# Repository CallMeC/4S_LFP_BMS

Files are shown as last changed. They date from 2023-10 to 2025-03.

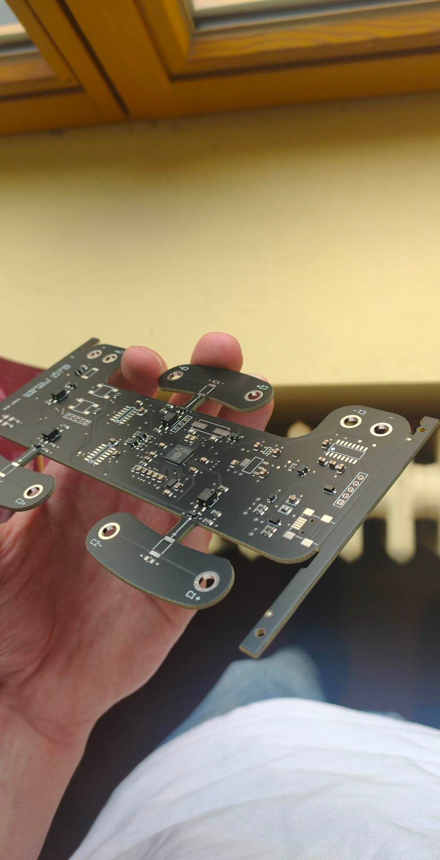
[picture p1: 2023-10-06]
Photos/NEW.jpg

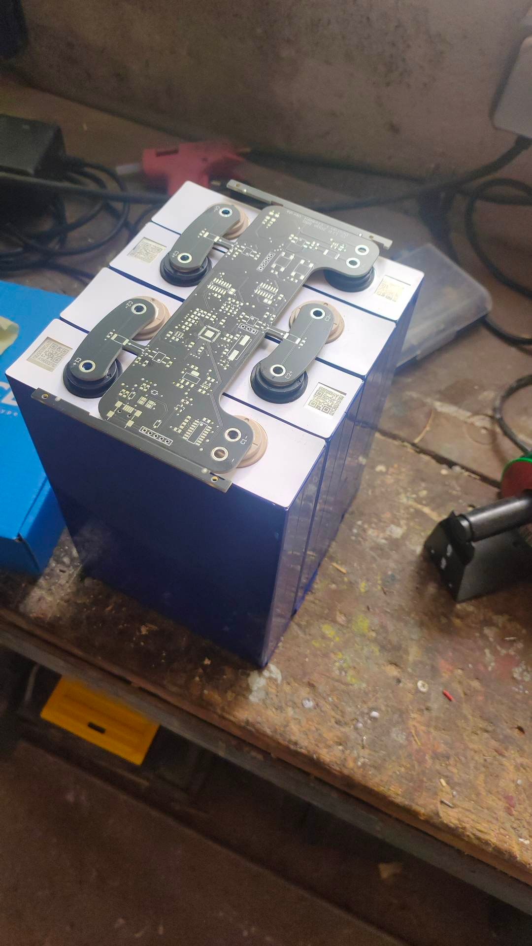
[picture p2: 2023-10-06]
Photos/ON_CELLS.jpg

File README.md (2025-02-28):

# 4S Lithium Iron Phosphate BMS RP2040 based
This BMS is intented to be used with EVE LF105 LFP cells. It goes on top of them, and is attached thanks to screws. The busbar is inside the PCB.

# Capabilities
The BMS can output up to 200A continuously and 400 peak. I tried to jumpstart a car, it works without problem.
The output voltage depends on capacity, a connctor was placed in order to add a daughter card to add USB-C power delivery capability.

# Features
This BMS is ables to :
- charge / discharge cells independently
- monitor voltage of each cell
- monitor temperature of group of cells
- monitor current accurately thanks to an inside shunt

# Performance
The BMS has the following characteristics :
- 4S Lithium Capability (LiFePO4)
- 12V Power Output
- 200A Continuous & 400A Peak current capability
- 1A Balancing current
- High accuracy cell voltage measurement
- Cell temperature measurement
- High accuracy current measurement
- Daisy-chaining capability (in case of pack)
- CAN 2.0 Communication
- Deep-Sleep mode with auto wake-up capbility
- Computer monitoring
- Active balancing extension board
- EEPROM

# Software
This BMS is based on the RP2040, the software is in early stage and not fully functionnal and tested yet.
Nevertheless, it can communicate to a computer by UART through USB. This way we can easily monitor the different cells caracteristics.

# Preview
2024-07-21-15-53-03-ezgif com-optimize

QT C++ Programm to visualise BMS characteristics in real time.

Assembly View

TOP_VIEW

SIDE_VIEW

PCB Preview


Capture d'écran 2024-02-19 112637




# Thanks
Thanks to @Ustan26 for his great help reviewing code !

# License
MIT License

Copyright (c) 2024 Clément VERDA

Permission is hereby granted, free of charge, to any person obtaining a copy
of this software and associated documentation files (the "Software"), to deal
in the Software without restriction, including without limitation the rights
to use, copy, modify, merge, publish, distribute, sublicense, and/or sell
copies of the Software, and to permit persons to whom the Software is
furnished to do so, subject to the following conditions:

The above copyright notice and this permission notice shall be included in all
copies or substantial portions of the Software.

THE SOFTWARE IS PROVIDED "AS IS", WITHOUT WARRANTY OF ANY KIND, EXPRESS OR
IMPLIED, INCLUDING BUT NOT LIMITED TO THE WARRANTIES OF MERCHANTABILITY,
FITNESS FOR A PARTICULAR PURPOSE AND NONINFRINGEMENT. IN NO EVENT SHALL THE
AUTHORS OR COPYRIGHT HOLDERS BE LIABLE FOR ANY CLAIM, DAMAGES OR OTHER
LIABILITY, WHETHER IN AN ACTION OF CONTRACT, TORT OR OTHERWISE, ARISING FROM,
OUT OF OR IN CONNECTION WITH THE SOFTWARE OR THE USE OR OTHER DEALINGS IN THE
SOFTWARE.

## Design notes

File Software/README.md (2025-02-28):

# Software
You will find here :
- BMS firmware
- Computer user-interface

This project utilizes work from the following GitHub repository: 
 
1. [Repository 1 URL](https://github.com/KevinOConnor/can2040) by [KevinOConnor ](https://github.com/KevinOConnor) 
   - Used the canRP2040 lib from this repository for CAN implementation on RP2040 MCU. 
   - Licensed under the GPL-3.0 license.

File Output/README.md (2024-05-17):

# PCB
Here are the PCB files of the v1.
A v2 is on the way.

# PCB Stackup
The PCB is intended to be manufactured by JLCPCB on a 4 layer stackup.
The outer layers should be at least 70µm copper height.
The inner layers should be at least 35 µm.
This allows the use of PCB for a busbar.

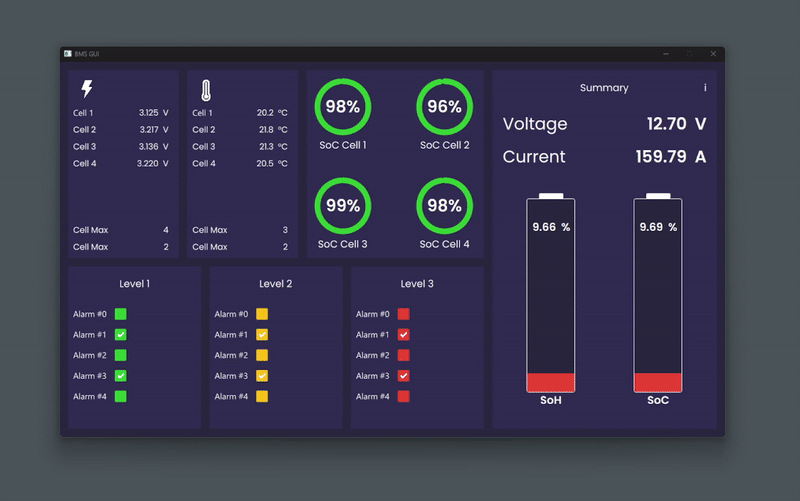
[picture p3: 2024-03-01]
Photos/BMS_GUI_PREVIEW.gif

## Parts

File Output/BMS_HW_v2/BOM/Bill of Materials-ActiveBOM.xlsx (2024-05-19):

Name | Designator | LCSC_Part_# | Description
CC0805KRX7R8BB104 | C1 | C49678 | CAP CER 0.1UF 25V X7R 0805
CC0805KRX7R8BB104 | C2 | C49678 | CAP CER 0.1UF 25V X7R 0805
CC0805KRX7R8BB104 | C3 | C49678 | CAP CER 0.1UF 25V X7R 0805
CL21A106KACLRNC | C4 | C49678 | CL21 Series 0805 10uF 25V ±10% Tolerance X5R Multilayer Ceramic Chip Capacitor
CL21A106KACLRNC | C5 |  | CL21 Series 0805 10uF 25V ±10% Tolerance X5R Multilayer Ceramic Chip Capacitor
CL21A106KACLRNC | C6 | C88484 | CL21 Series 0805 10uF 25V ±10% Tolerance X5R Multilayer Ceramic Chip Capacitor
CL21A106KACLRNC | C7 | C49678 | CL21 Series 0805 10uF 25V ±10% Tolerance X5R Multilayer Ceramic Chip Capacitor
CL21A106KACLRNC | C8 | C437557 | CL21 Series 0805 10uF 25V ±10% Tolerance X5R Multilayer Ceramic Chip Capacitor
CL21A106KACLRNC | C9 | C49678 | CL21 Series 0805 10uF 25V ±10% Tolerance X5R Multilayer Ceramic Chip Capacitor
CL21A106KACLRNC | C10 | C88484 | CL21 Series 0805 10uF 25V ±10% Tolerance X5R Multilayer Ceramic Chip Capacitor
CC0805KRX7R8BB104 | C11 | C28323 | CAP CER 0.1UF 25V X7R 0805
CC0805KRX7R8BB104 | C12 | C28323 | CAP CER 0.1UF 25V X7R 0805
CL21A106KACLRNC | C13 | C49678 | CL21 Series 0805 10uF 25V ±10% Tolerance X5R Multilayer Ceramic Chip Capacitor
CC0805KRX7R8BB104 | C14 | C377773 | CAP CER 0.1UF 25V X7R 0805
CC0805KRX7R8BB104 | C15 | C49678 | CAP CER 0.1UF 25V X7R 0805
CC0805KRX7R8BB104 | C16 | C377773 | CAP CER 0.1UF 25V X7R 0805
CC0805KRX7R8BB104 | C17 | C49678 | CAP CER 0.1UF 25V X7R 0805
CC0805KRX7R8BB104 | C18 | C49678 | CAP CER 0.1UF 25V X7R 0805
CC0805KRX7R8BB104 | C19 | C377773 | CAP CER 0.1UF 25V X7R 0805
CC0805KRX7R8BB104 | C20 | C49678 | CAP CER 0.1UF 25V X7R 0805
CC0805KRX7R8BB104 | C21 | C49678 | CAP CER 0.1UF 25V X7R 0805
CC0805KRX7R8BB104 | C22 | C49678 | CAP CER 0.1UF 25V X7R 0805
CC0805KRX7R8BB104 | C23 | C49678 | CAP CER 0.1UF 25V X7R 0805
CC0805KRX7R8BB104 | C24 | C49678 | CAP CER 0.1UF 25V X7R 0805
CC0805KRX7R8BB104 | C25 | C49678 | CAP CER 0.1UF 25V X7R 0805
CC0805KRX7R8BB104 | C26 | C49678 | CAP CER 0.1UF 25V X7R 0805
CC0805KRX7R8BB104 | C27 | C1808 | CAP CER 0.1UF 25V X7R 0805
CC0805KRX7R8BB104 | C28 | C1808 | CAP CER 0.1UF 25V X7R 0805
CC0805KRX7R8BB104 | C29 | C377773 | CAP CER 0.1UF 25V X7R 0805
CL21A106KACLRNC | C30 | C961512 | CL21 Series 0805 10uF 25V ±10% Tolerance X5R Multilayer Ceramic Chip Capacitor
CL21A106KACLRNC | C31 | C49678 | CL21 Series 0805 10uF 25V ±10% Tolerance X5R Multilayer Ceramic Chip Capacitor
CL21A106KACLRNC | C32 | C961512 | CL21 Series 0805 10uF 25V ±10% Tolerance X5R Multilayer Ceramic Chip Capacitor
CC0805KRX7R8BB104 | C33 | C49678 | CAP CER 0.1UF 25V X7R 0805
CL21A106KACLRNC | C34 | C88484 | CL21 Series 0805 10uF 25V ±10% Tolerance X5R Multilayer Ceramic Chip Capacitor
CL21A106KACLRNC | C35 | C49678 | CL21 Series 0805 10uF 25V ±10% Tolerance X5R Multilayer Ceramic Chip Capacitor
CC0805KRX7R8BB104 | C36 | C49678 | CAP CER 0.1UF 25V X7R 0805
CC0805KRX7R8BB104 | C37 | C49678 | CAP CER 0.1UF 25V X7R 0805
CC0805KRX7R8BB104 | C38 | C49678 | CAP CER 0.1UF 25V X7R 0805
CC0805KRX7R8BB104 | C39 | C49678 | CAP CER 0.1UF 25V X7R 0805
CC0805KRX7R8BB104 | C40 | C49678 | CAP CER 0.1UF 25V X7R 0805
CC0805KRX7R8BB104 | C41 | C49678 | CAP CER 0.1UF 25V X7R 0805
CC0805KRX7R8BB104 | C42 | C49678 | CAP CER 0.1UF 25V X7R 0805
CC0805KRX7R8BB104 | C43 | C1710 | CAP CER 0.1UF 25V X7R 0805
CC0805KRX7R8BB104 | C44 | C1710 | CAP CER 0.1UF 25V X7R 0805
CC0805KRX7R8BB104 | C45 | C1710 | CAP CER 0.1UF 25V X7R 0805
CC0805KRX7R8BB104 | C46 | C1710 | CAP CER 0.1UF 25V X7R 0805
CC0805KRX7R8BB104 | C47 | C1710 | CAP CER 0.1UF 25V X7R 0805
CC0805KRX7R8BB104 | C48 | C49678 | CAP CER 0.1UF 25V X7R 0805
CC0805KRX7R8BB104 | C49 | C49678 | CAP CER 0.1UF 25V X7R 0805
CC0805KRX7R8BB104 | C50 | C49678 | CAP CER 0.1UF 25V X7R 0805
LF105 Cell Terminal | Cell1- |  | LF105 Cell Terminal
LF105 Cell Terminal | Cell1+ |  | LF105 Cell Terminal
LF105 Cell Terminal | Cell2- |  | LF105 Cell Terminal
LF105 Cell Terminal | Cell2+ |  | LF105 Cell Terminal
LF105 Cell Terminal | Cell3- |  | LF105 Cell Terminal
LF105 Cell Terminal | Cell3+ |  | LF105 Cell Terminal
LF105 Cell Terminal | Cell4- |  | LF105 Cell Terminal
LF105 Cell Terminal | Cell4+ |  | LF105 Cell Terminal
ZMM3V3 | D1 |  | Zener ZMM3V3
B340AE-13 | D2 | C168859 | Rectifier Diode, Schottky, 1 Phase, 1 Element, 3A, 40V V(RRM), Silicon
B340AE-13 | D3 | C168859 | Rectifier Diode, Schottky, 1 Phase, 1 Element, 3A, 40V V(RRM), Silicon
82356050050 | D4 | C9900055762
HSMG-C170 | D5 | C84256 | Chip LED, Green, 2.2 V, -40 to 85 degC, 2-Pin SMD, Pb-Free, Tape and Reel
SS14 | D6 | C2480 | DIODE SCHOTTKY 40V 1A SMA
SS14 | D7 | C2480 | DIODE SCHOTTKY 40V 1A SMA
SS14 | D8 | C2480 | DIODE SCHOTTKY 40V 1A SMA
TPD2E2U06DCKR | D9 | C1855726 | Q100 TO CATALOG SPIN OF TPD2E2U0
HSMG-C170 | D10 | C84256 | Chip LED, Green, 2.2 V, -40 to 85 degC, 2-Pin SMD, Pb-Free, Tape and Reel
LF105 Cell Terminal | J1 |  | LF105 Cell Terminal
LF105 Cell Terminal | J2 |  | LF105 Cell Terminal
87224-3 | J3 |  | Board Connector, 3 Contact(s), 1 Row(s), Male, Straight, 0.1 inch Pitch, Solder Terminal, Black Insulator, Receptacle
22-27-2021 | J4 | C293316 | Male Header, Pitch 2.54 mm, 1 x 2 Position, Height 11.7 mm, Tail Length 3.56 mm, 0 to 75 degC, RoHS, Bulk
1565749-4 | J5 |  | Automotive Connectors 025 4POS CAP ASY SELECTIVE-TIN
MUSB-05-S-B-SM-A | J6 | C5362859 | CONN RCPT USB2.0 MINI B SMD R/A
1565749-4 | J7 |  | Automotive Connectors 025 4POS CAP ASY SELECTIVE-TIN
TSW-104-08-L-S | J8 |  | Board Connector, 4 Contact(s), 1 Row(s), Male, Straight, Solder Terminal
90120-0125 | J9 |  | 90120-0125 2.54mm Pitch C-Grid III Header, Single Row, Vertical, 5 Circuits, Tin (Sn) Plating
SRR1260-5R6Y | L1 | C2761913 | General Purpose Inductor, 5.6uH, 30%, 1 Element, Ferrite-Core, SMD, 4949
BSS138 | Q1 | C112239 | N-Channel Logic Level Enhancement Mode Field Effect Transistor, 220 mA, 50 V, -55 to 150 degC, 3-Pin SOT-23, RoHS, Tape and Reel
BSS138 | Q2 | C112239 | N-Channel Logic Level Enhancement Mode Field Effect Transistor, 220 mA, 50 V, -55 to 150 degC, 3-Pin SOT-23, RoHS, Tape and Reel
BSS138 | Q3 | C112239 | N-Channel Logic Level Enhancement Mode Field Effect Transistor, 220 mA, 50 V, -55 to 150 degC, 3-Pin SOT-23, RoHS, Tape and Reel
AO3400A | Q4 | C20917 | MOSFET N-CH 30V 5.7A SOT23
AO3400A | Q5 | C20917 | MOSFET N-CH 30V 5.7A SOT23
AO3400A | Q6 | C20917 | MOSFET N-CH 30V 5.7A SOT23
AO3400A | Q7 | C20917 | MOSFET N-CH 30V 5.7A SOT23
BSS138 | Q8 | C112239 | N-Channel Logic Level Enhancement Mode Field Effect Transistor, 220 mA, 50 V, -55 to 150 degC, 3-Pin SOT-23, RoHS, Tape and Reel
RT0805DRE074K7L | R1 | C149504 | RES SMD 4.7K OHM 0.5% 1/8W 0805
RT0805DRE074K7L | R2 | C149504 | RES SMD 4.7K OHM 0.5% 1/8W 0805
RT0805DRE074K7L | R3 | C149504 | RES SMD 4.7K OHM 0.5% 1/8W 0805
RT0805DRE074K7L | R4 | C149504 | RES SMD 4.7K OHM 0.5% 1/8W 0805
RT0805DRE074K7L | R5 |  | RES SMD 4.7K OHM 0.5% 1/8W 0805
RT0805DRE074K7L | R6 | C95968 | RES SMD 4.7K OHM 0.5% 1/8W 0805
RT0805DRE074K7L | R7 | C95968 | RES SMD 4.7K OHM 0.5% 1/8W 0805
RT0805DRE074K7L | R8 | C95968 | RES SMD 4.7K OHM 0.5% 1/8W 0805
RT0805DRE074K7L | R9 | C95968 | RES SMD 4.7K OHM 0.5% 1/8W 0805
RT0805DRE074K7L | R10 | C17470 | RES SMD 4.7K OHM 0.5% 1/8W 0805
RT0805DRE074K7L | R11 | C2828840 | RES SMD 4.7K OHM 0.5% 1/8W 0805
RT0805DRE074K7L | R12 | C17621 | RES SMD 4.7K OHM 0.5% 1/8W 0805
RT0805DRE074K7L | R13 | C17414 | RES SMD 4.7K OHM 0.5% 1/8W 0805
RT0805DRE074K7L | R14 | C17414 | RES SMD 4.7K OHM 0.5% 1/8W 0805
RT0805DRE074K7L | R15 | C17414 | RES SMD 4.7K OHM 0.5% 1/8W 0805
RT0805DRE074K7L | R16 | C17414 | RES SMD 4.7K OHM 0.5% 1/8W 0805
PCB_SHUNT_200A | R17 |  | Shunt
RT0805DRE074K7L | R18 | C2828840 | RES SMD 4.7K OHM 0.5% 1/8W 0805
RT0805DRE074K7L | R19 | C17621 | RES SMD 4.7K OHM 0.5% 1/8W 0805
RT0805DRE074K7L | R20 | C2828840 | RES SMD 4.7K OHM 0.5% 1/8W 0805
RT0805DRE074K7L | R21 | C218616 | RES SMD 4.7K OHM 0.5% 1/8W 0805
RT0805DRE074K7L | R22 | C17414 | RES SMD 4.7K OHM 0.5% 1/8W 0805
RT0805DRE074K7L | R23 | C4382 | RES SMD 4.7K OHM 0.5% 1/8W 0805
RT0805DRE074K7L | R24 | C17513 | RES SMD 4.7K OHM 0.5% 1/8W 0805
RT0805DRE074K7L | R25 | C17414 | RES SMD 4.7K OHM 0.5% 1/8W 0805
RT0805DRE074K7L | R26 |  | RES SMD 4.7K OHM 0.5% 1/8W 0805
RT0805DRE074K7L | R27 |  | RES SMD 4.7K OHM 0.5% 1/8W 0805
RT0805DRE074K7L | R28 | C17594 | RES SMD 4.7K OHM 0.5% 1/8W 0805
RT0805DRE074K7L | R29 | C17594 | RES SMD 4.7K OHM 0.5% 1/8W 0805
RT0805DRE074K7L | R30 |  | RES SMD 4.7K OHM 0.5% 1/8W 0805
RT0805DRE074K7L | R31 | C17414 | RES SMD 4.7K OHM 0.5% 1/8W 0805
RT0805DRE074K7L | R32 | C25271 | RES SMD 4.7K OHM 0.5% 1/8W 0805
RT0805DRE074K7L | R33 | C17540 | RES SMD 4.7K OHM 0.5% 1/8W 0805
35224R7JT | R34 | C3924519 | Fixed Resistor, Metal Glaze/thick Film, 3W, 4.7ohm, 250V, 5% +/-Tol, 400ppm/Cel, Surface Mount, 2512
35224R7JT | R35 | C3924519 | Fixed Resistor, Metal Glaze/thick Film, 3W, 4.7ohm, 250V, 5% +/-Tol, 400ppm/Cel, Surface Mount, 2512
RT0805DRE074K7L | R36 | C17655 | RES SMD 4.7K OHM 0.5% 1/8W 0805
RT0805DRE074K7L | R37 | C17655 | RES SMD 4.7K OHM 0.5% 1/8W 0805
RT0805DRE074K7L | R38 | C17408 | RES SMD 4.7K OHM 0.5% 1/8W 0805
RT0805DRE074K7L | R39 | C17408 | RES SMD 4.7K OHM 0.5% 1/8W 0805
RT0805DRE074K7L | R40 | C865503 | RES SMD 4.7K OHM 0.5% 1/8W 0805
RT0805DRE074K7L | R41 | C149504 | RES SMD 4.7K OHM 0.5% 1/8W 0805
RT0805DRE074K7L | R42 | C865503 | RES SMD 4.7K OHM 0.5% 1/8W 0805
RT0805DRE074K7L | R43 | C149504 | RES SMD 4.7K OHM 0.5% 1/8W 0805
35224R7JT | R44 | C3924519 | Fixed Resistor, Metal Glaze/thick Film, 3W, 4.7ohm, 250V, 5% +/-Tol, 400ppm/Cel, Surface Mount, 2512
RT0805DRE074K7L | R45 | C17655 | RES SMD 4.7K OHM 0.5% 1/8W 0805
RT0805DRE074K7L | R46 | C17408 | RES SMD 4.7K OHM 0.5% 1/8W 0805
RT0805DRE074K7L | R47 | C865503 | RES SMD 4.7K OHM 0.5% 1/8W 0805
RT0805DRE074K7L | R48 | C149504 | RES SMD 4.7K OHM 0.5% 1/8W 0805
35224R7JT | R49 | C3924519 | Fixed Resistor, Metal Glaze/thick Film, 3W, 4.7ohm, 250V, 5% +/-Tol, 400ppm/Cel, Surface Mount, 2512
RT0805DRE074K7L | R50 | C17655 | RES SMD 4.7K OHM 0.5% 1/8W 0805
RT0805DRE074K7L | R51 | C17408 | RES SMD 4.7K OHM 0.5% 1/8W 0805
RT0805DRE074K7L | R52 | C865503 | RES SMD 4.7K OHM 0.5% 1/8W 0805
RT0805DRE074K7L | R53 | C149504 | RES SMD 4.7K OHM 0.5% 1/8W 0805
RT0805DRE074K7L | R54 | C17757 | RES SMD 4.7K OHM 0.5% 1/8W 0805
RT0805DRE074K7L | R55 | C17757 | RES SMD 4.7K OHM 0.5% 1/8W 0805
RT0805DRE074K7L | R56 |  | RES SMD 4.7K OHM 0.5% 1/8W 0805
RT0805DRE074K7L | R57 | C17408 | RES SMD 4.7K OHM 0.5% 1/8W 0805
RT0805DRE074K7L | R58 | C149504 | RES SMD 4.7K OHM 0.5% 1/8W 0805
RT0805DRE074K7L | R59 | C17655 | RES SMD 4.7K OHM 0.5% 1/8W 0805
RT0805DRE074K7L | R60 | C865503 | RES SMD 4.7K OHM 0.5% 1/8W 0805
FSM4JSMATR | SW1 |  | Micro Miniature Push Button Switch FSM JSM, 50 mA, -35 to 85 degC, 4-Pin SMD, RoHS, Tape and Reel
FSM4JSMATR | SW2 |  | Micro Miniature Push Button Switch FSM JSM, 50 mA, -35 to 85 degC, 4-Pin SMD, RoHS, Tape and Reel
FSM4JSMATR | SW3 |  | Micro Miniature Push Button Switch FSM JSM, 50 mA, -35 to 85 degC, 4-Pin SMD, RoHS, Tape and Reel
Test point | TP1 |  | test point
Test point | TP2 |  | test point
Test point | TP3 |  | test point
Test point | TP4 |  | test point
Test point | TP5 |  | test point
Test point | TP6 |  | test point
Test point | TP7 |  | test point
Test point | TP8 |  | test point
Test point | TP9 |  | test point
Test point | TP10 |  | test point
Test point | TP11 |  | test point
Test point | TP12 |  | test point
Test point | TP13 |  | test point
Test point | TP14 |  | test point
Test point | TP15 |  | test point
Test point | TP16 |  | test point
Test point | TP17 |  | test point
Test point | TP18 |  | test point
Test point | TP19 |  | test point
Test point | TP20 |  | test point
Test point | TP21 |  | test point
Test point | TP22 |  | test point
Test point | TP23 |  | test point
Test point | TP24 |  | test point
Test point | TP25 |  | test point
Test point | TP26 |  | test point
Test point | TP27 |  | test point
Test point | TP28 |  | test point
Test point | TP30 |  | test point
Test point | TP31 |  | test point
Test point | TP32 |  | test point
Test point | TP33 |  | test point
Test point | TP34 |  | test point
Test point | TP35 |  | test point
Test point | TP36 |  | test point
Test point | TP37 |  | test point
Test point | TP38 |  | test point
Test point | TP39 |  | test point
Test point | TP40 |  | test point
Test point | TP41 |  | test point
MCP3424-E/SL | U1 | C640884 | 18-Bit, 4-Channel Analog-to-Digital Converter with I2C Interface and On-Board Reference, 14-Pin SOIC 150mil, Extended Temperature
INA180A1IDBVR | U2 | C116203 | IC CURR SENSE 1 CIRCUIT SOT23-5
MCP3424-E/SL | U3 | C640884 | 18-Bit, 4-Channel Analog-to-Digital Converter with I2C Interface and On-Board Reference, 14-Pin SOIC 150mil, Extended Temperature
TPS563300DRLR | U4 | C3200405 | TPS563300 3.8-V to 28-V, 3-A Synchronous Buck Converter in SOT583 Package
TPL5110DDCT | U5 | C125830 | IC OSC PROG TIMER TSOT23-6
AP2112M-3.3TRG1 | U6 | C5290219 | Fixed Positive LDO Regulator, 3.3V, 0.4V Dropout, CMOS, PDSO8
RP2040 | U7 | C2040 | RP2040 chip for Raspberry Pi Pico - ARMÂ® CortexÂ®-M0+ MCU 32-Bit
W25Q16JVUXIQ | U8 |  | IC FLASH 16MBIT SPI/QUAD 8USON
FODM217CR2V | U9 | C891189 | Transistor Output Optocoupler, 1-Element, 3750V Isolation
FODM217CR2V | U10 | C891189 | Transistor Output Optocoupler, 1-Element, 3750V Isolation
FODM217CR2V | U11 | C891189 | Transistor Output Optocoupler, 1-Element, 3750V Isolation
FODM217CR2V | U12 | C891189 | Transistor Output Optocoupler, 1-Element, 3750V Isolation
SN65HVD230DR | U13 | C12084 | Interface Circuit, 1-Trnsvr, BICMOS, PDSO8
FODM217CR2V | U14 | C891189 | Transistor Output Optocoupler, 1-Element, 3750V Isolation
AT24C32D-SSHM-B | U15 |  | IC EEPROM 32KBIT I2C 1MHZ 8SOIC
FL1200138 | X1 | C526612 | 12 MHz +/-15ppm Crystal 8pF 120 Ohms 4-SMD, No Lead

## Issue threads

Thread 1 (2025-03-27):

Docs: HowTo use in series?

hansbkk, 2025-03-27:
for 24V or 48V

If impossible, please state 12V design only

CallMeC, 2025-03-27:
Hi!
A single battery pack is 12V, and is meant to be used in series with other packs, only CAN communication and wakeup wire is needed.
I will update documentation accordingly.
Thanks!

Closed 2025-03-27.

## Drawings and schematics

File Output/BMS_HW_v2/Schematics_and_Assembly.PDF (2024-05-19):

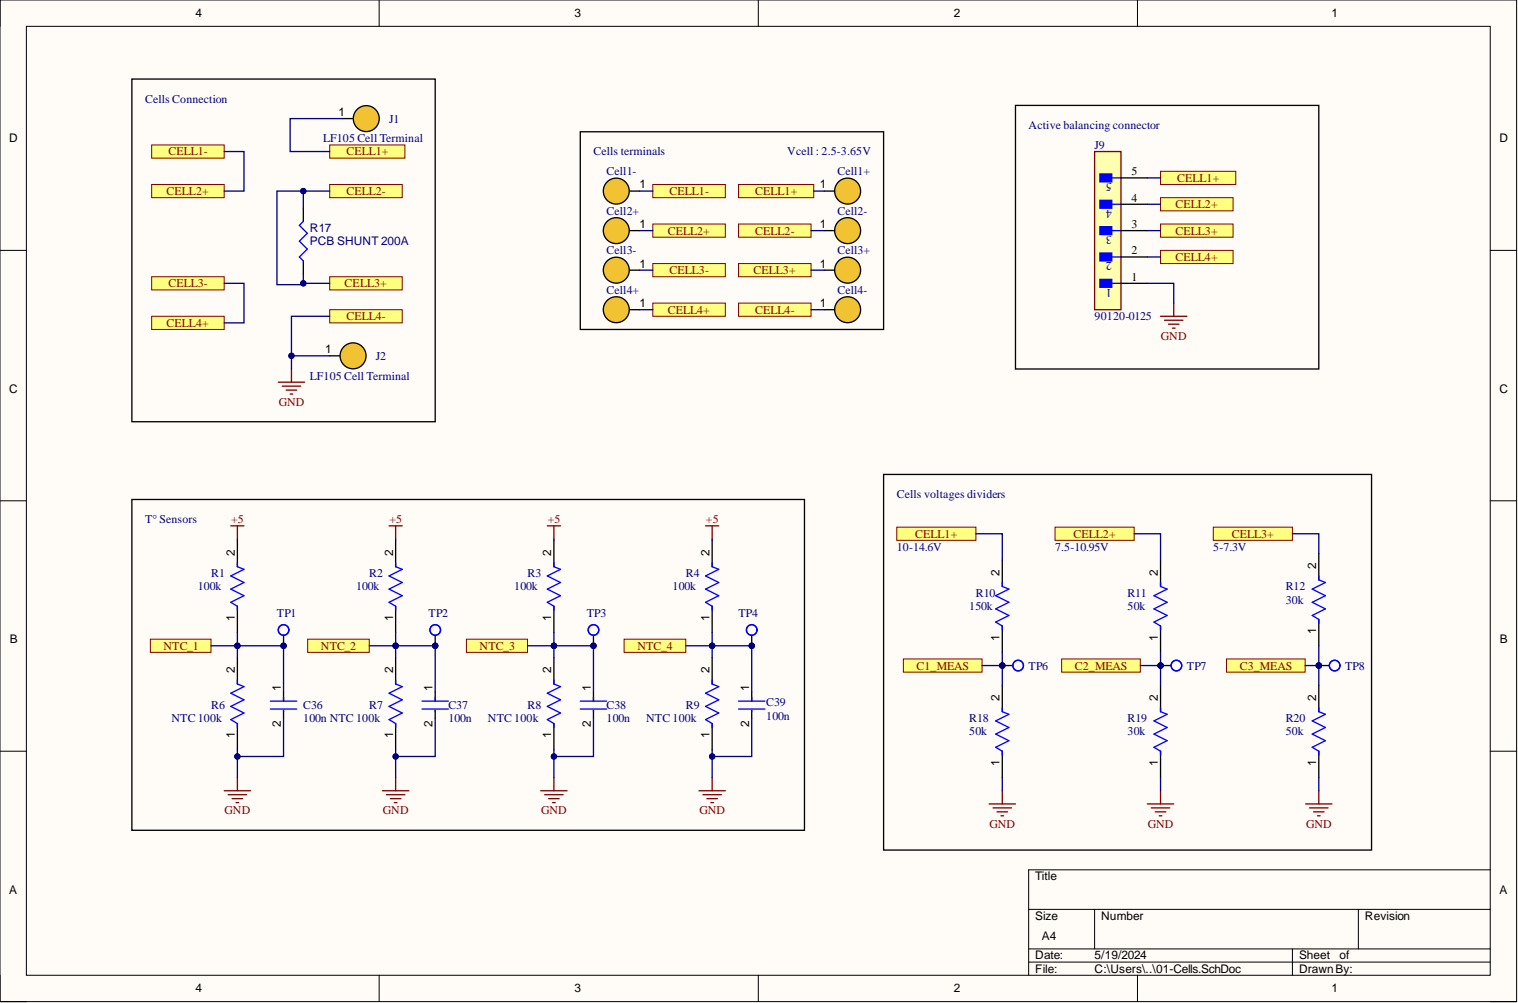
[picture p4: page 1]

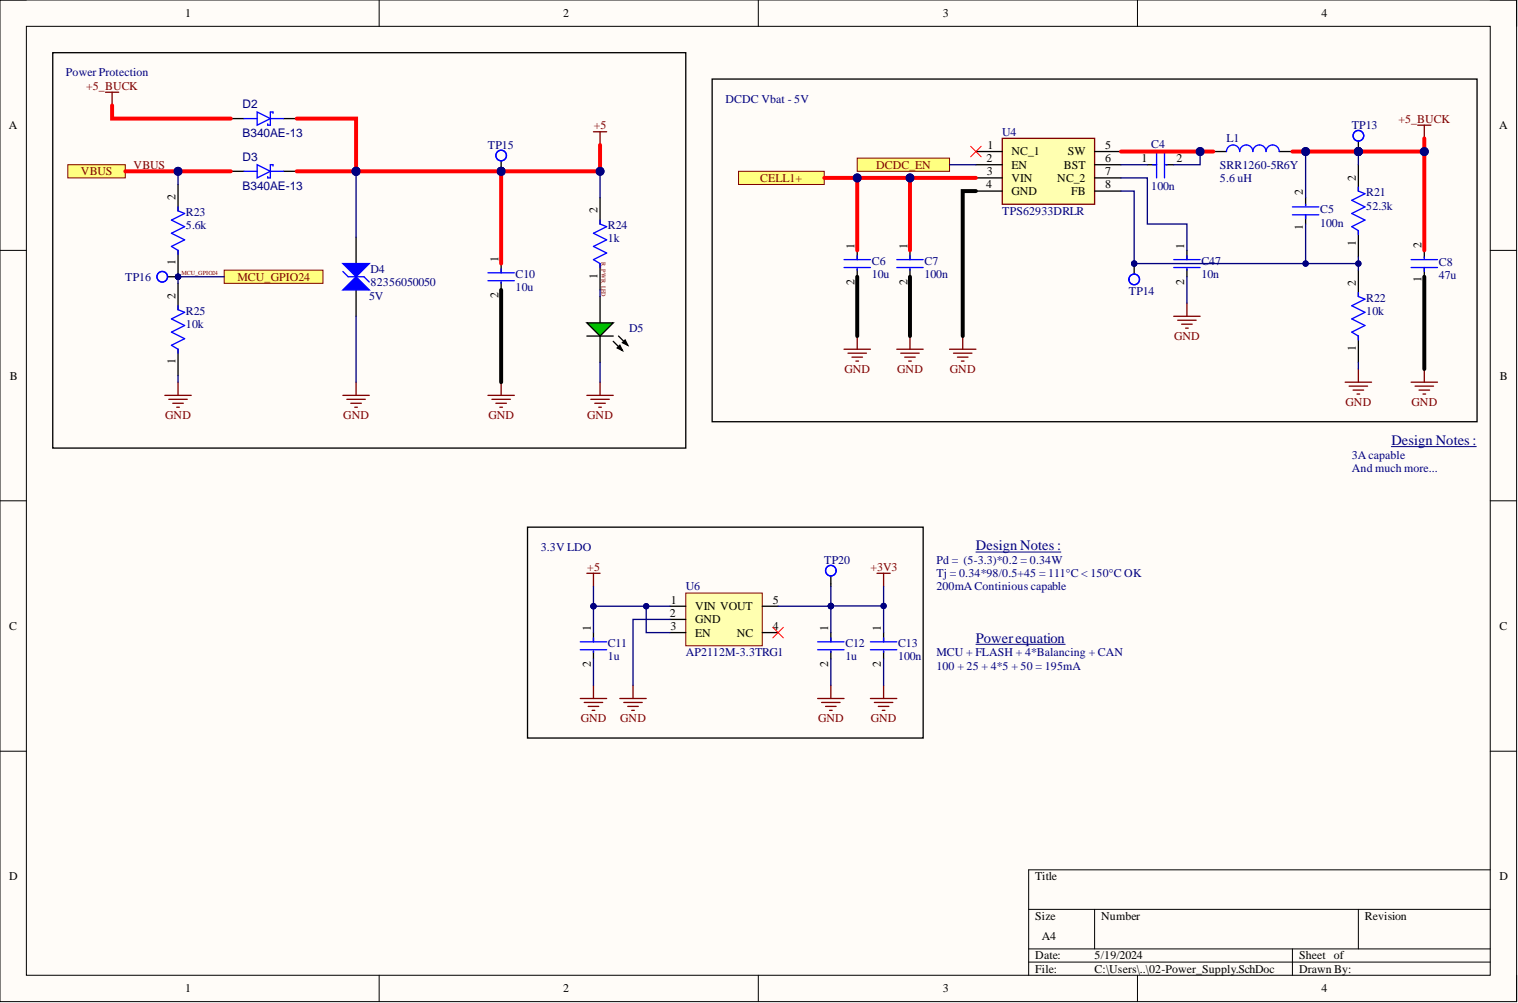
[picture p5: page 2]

GND 4 | 100n

MCU + FLASH + 4*Balancing + CAN

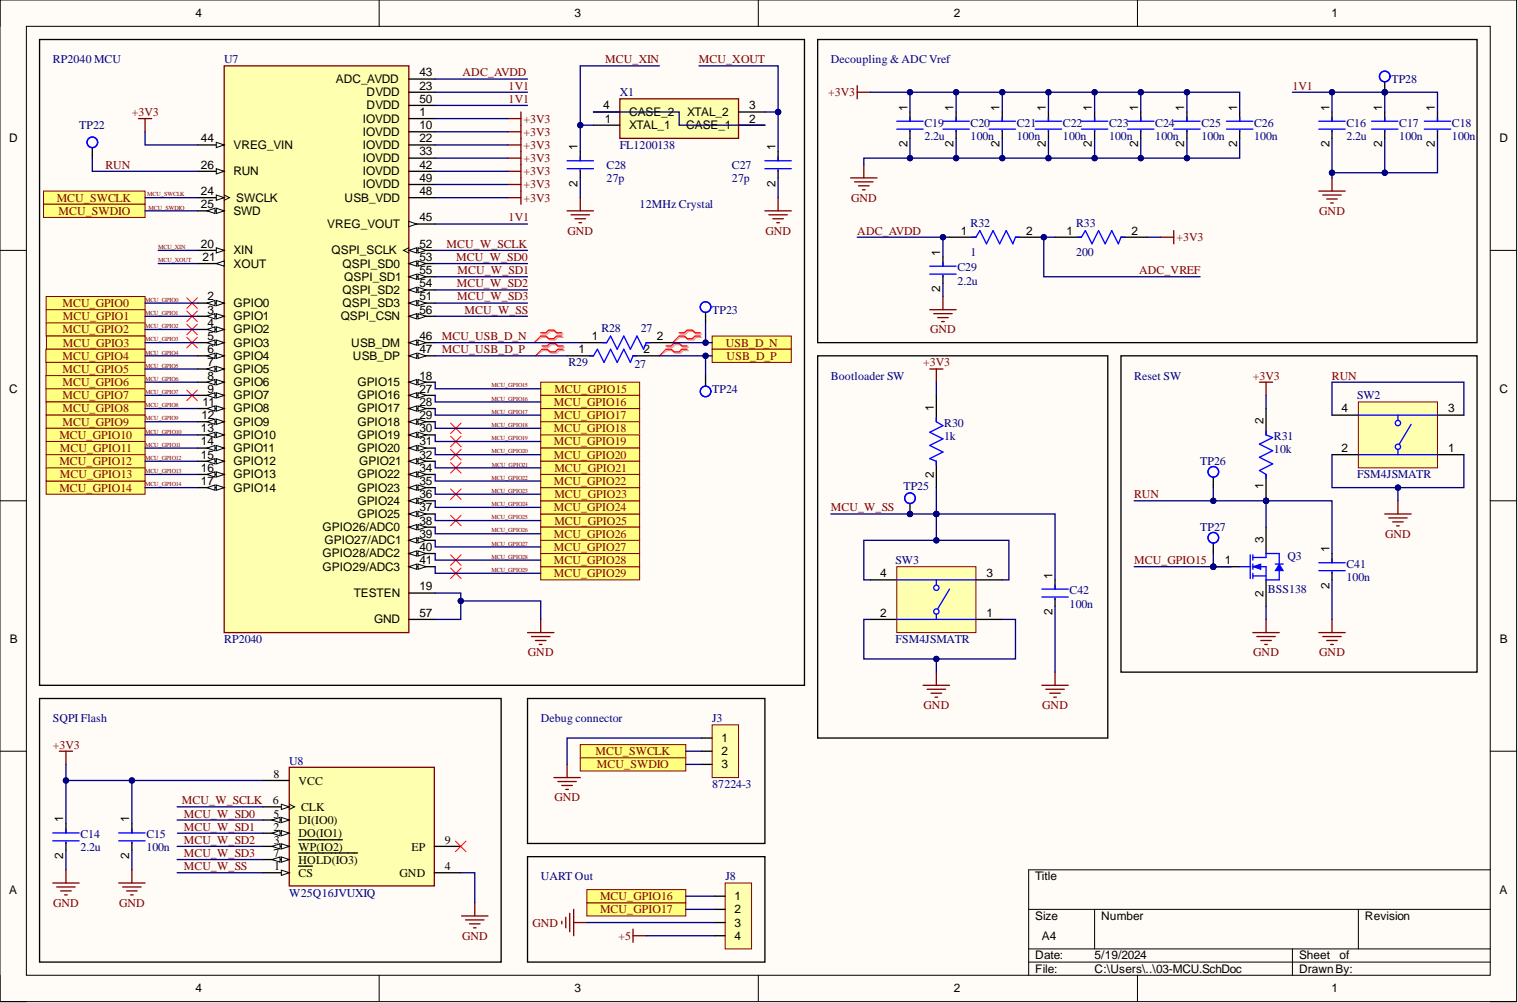
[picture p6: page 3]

MCU_GPIO8 | GPIO8 11 | MCU_GPIO16 | MCU_GPIO16
MCU_GPIO9 | GPIO9 12 | MCU_GPIO17 | MCU_GPIO17
MCU_GPIO10 | GPIO10 13 | MCU_GPIO18 | MCU_GPIO18
MCU_GPIO11 | GPIO11 14 | MCU_GPIO19 | MCU_GPIO19
MCU_GPIO12 | GPIO12 15 | MCU_GPIO20 | MCU_GPIO20
MCU_GPIO13 | GPIO13 16 | MCU_GPIO21 | MCU_GPIO21
MCU_GPIO14 | GPIO14 17 | MCU_GPIO22 | MCU_GPIO22

MCU_GPIO23 | MCU_GPIO23

MCU_GPIO24 | MCU_GPIO24

MCU_GPIO25 | MCU_GPIO25

MCU_GPIO26 | MCU_GPIO26

MCU_GPIO27 | MCU_GPIO27

MCU_GPIO29 | MCU_GPIO29

GND

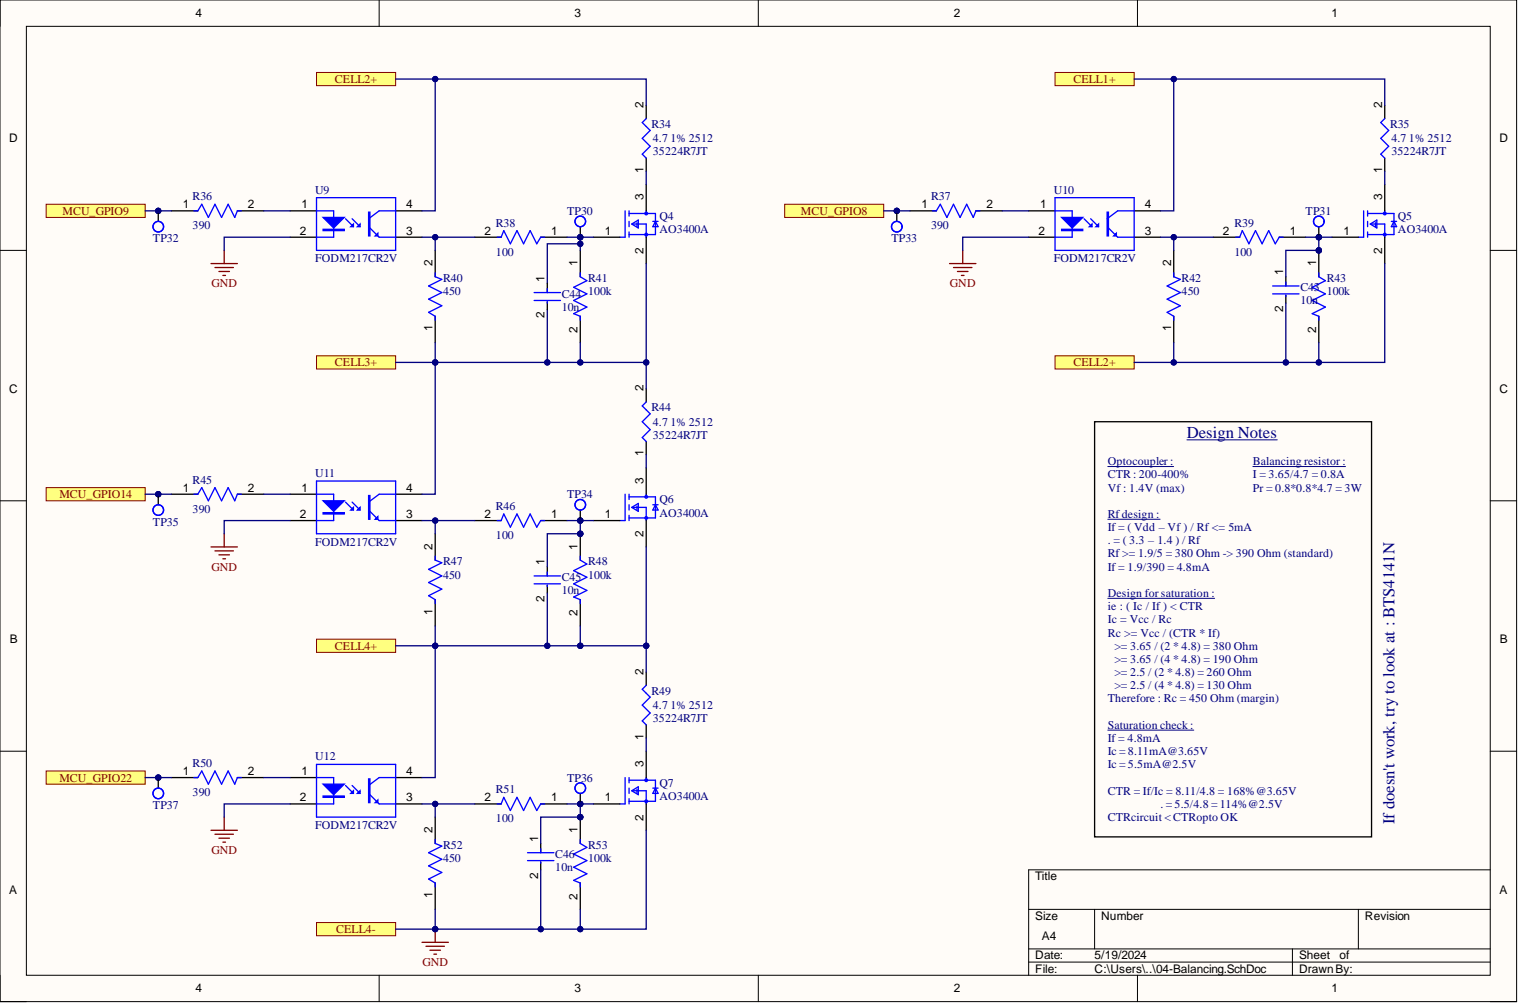
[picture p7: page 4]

Rf design :
If = ( Vdd – Vf ) / Rf <= 5mA
Rf >= 1.9/5 = 380 Ohm -> 390 Ohm (standard)

Design for saturation :
ie : ( Ic / If ) < CTR
Ic = Vcc / Rc
Rc >= Vcc / (CTR * If)
>= 3.65 / (2 * 4.8) = 380 Ohm
>= 3.65 / (4 * 4.8) = 190 Ohm
>= 2.5 / (2 * 4.8) = 260 Ohm
>= 2.5 / (4 * 4.8) = 130 Ohm
Therefore : Rc = 450 Ohm (margin)

If doesn't work, try to look at : B

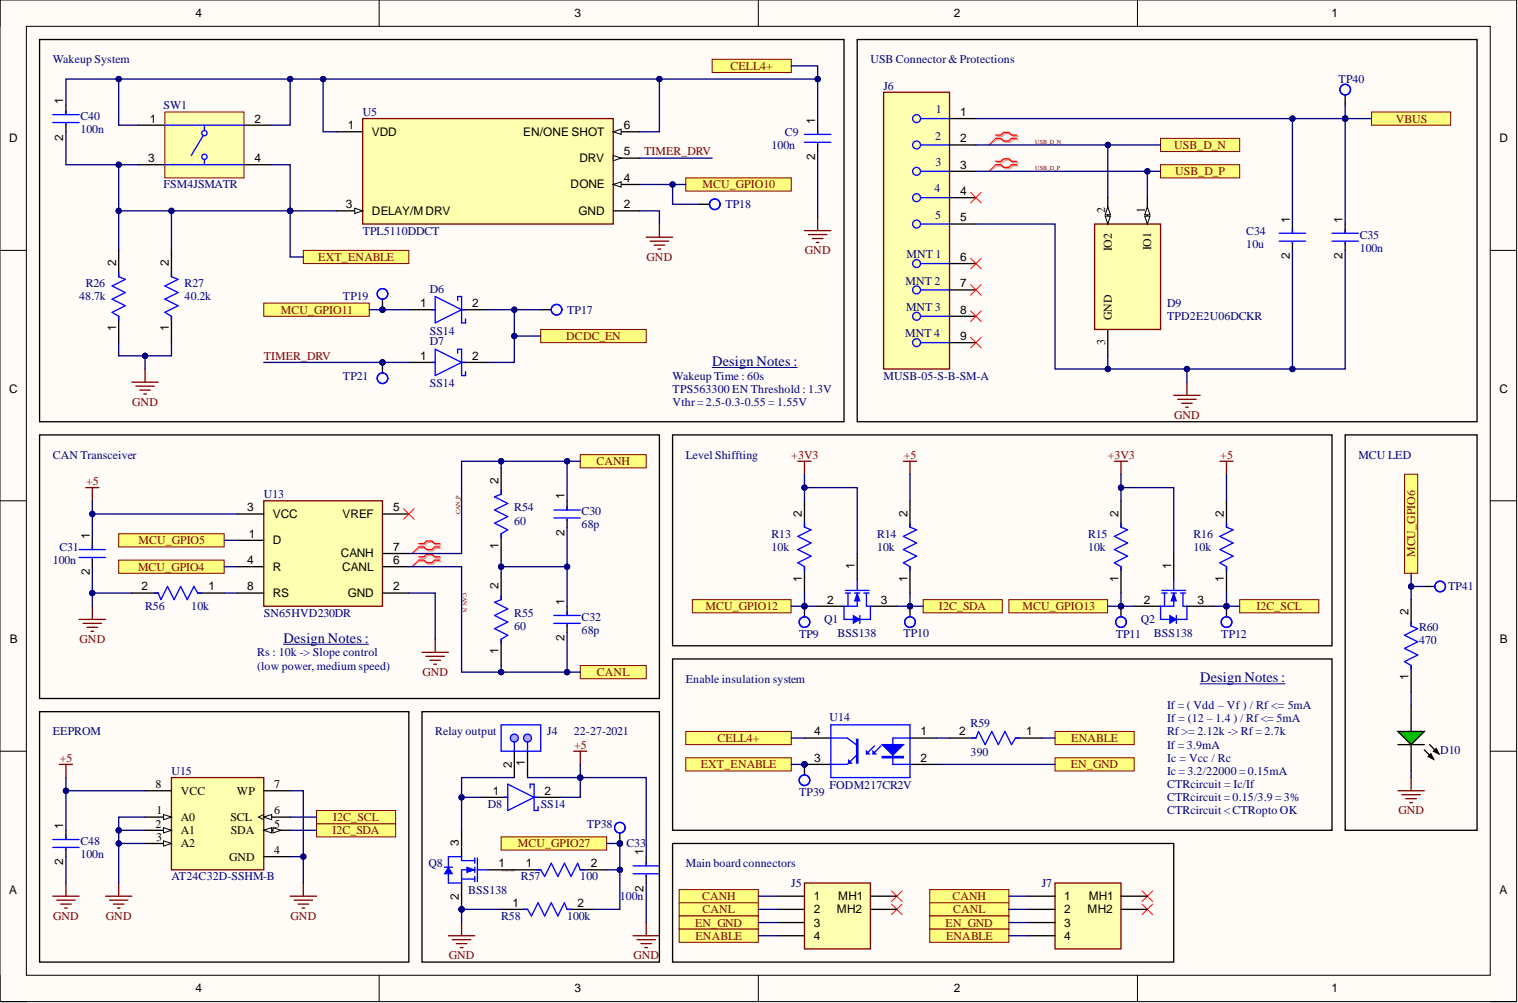
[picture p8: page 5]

SN65HVD230DR
Design Notes :
Rs : 10k -> Slope control
(low power, medium speed)

If = ( Vdd – Vf ) / Rf <= 5mA
Ic = Vcc / Rc
CTRcircuit = Ic/If
CTRcircuit = 0.15/3.9 = 3%
CTRcircuit < CTRopto OK

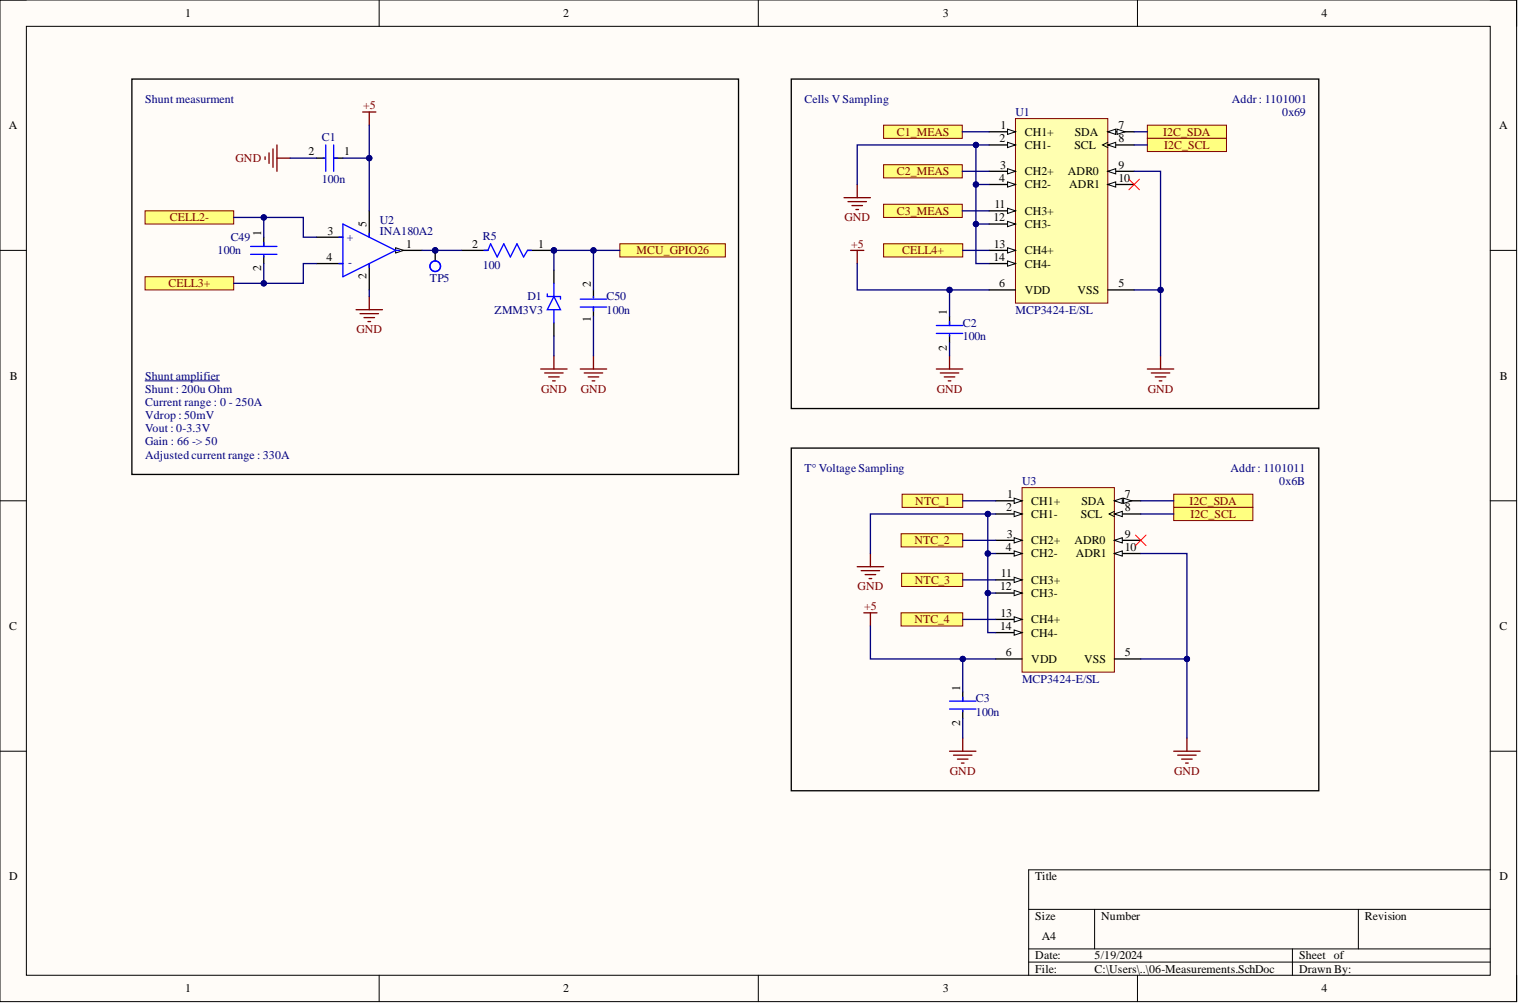
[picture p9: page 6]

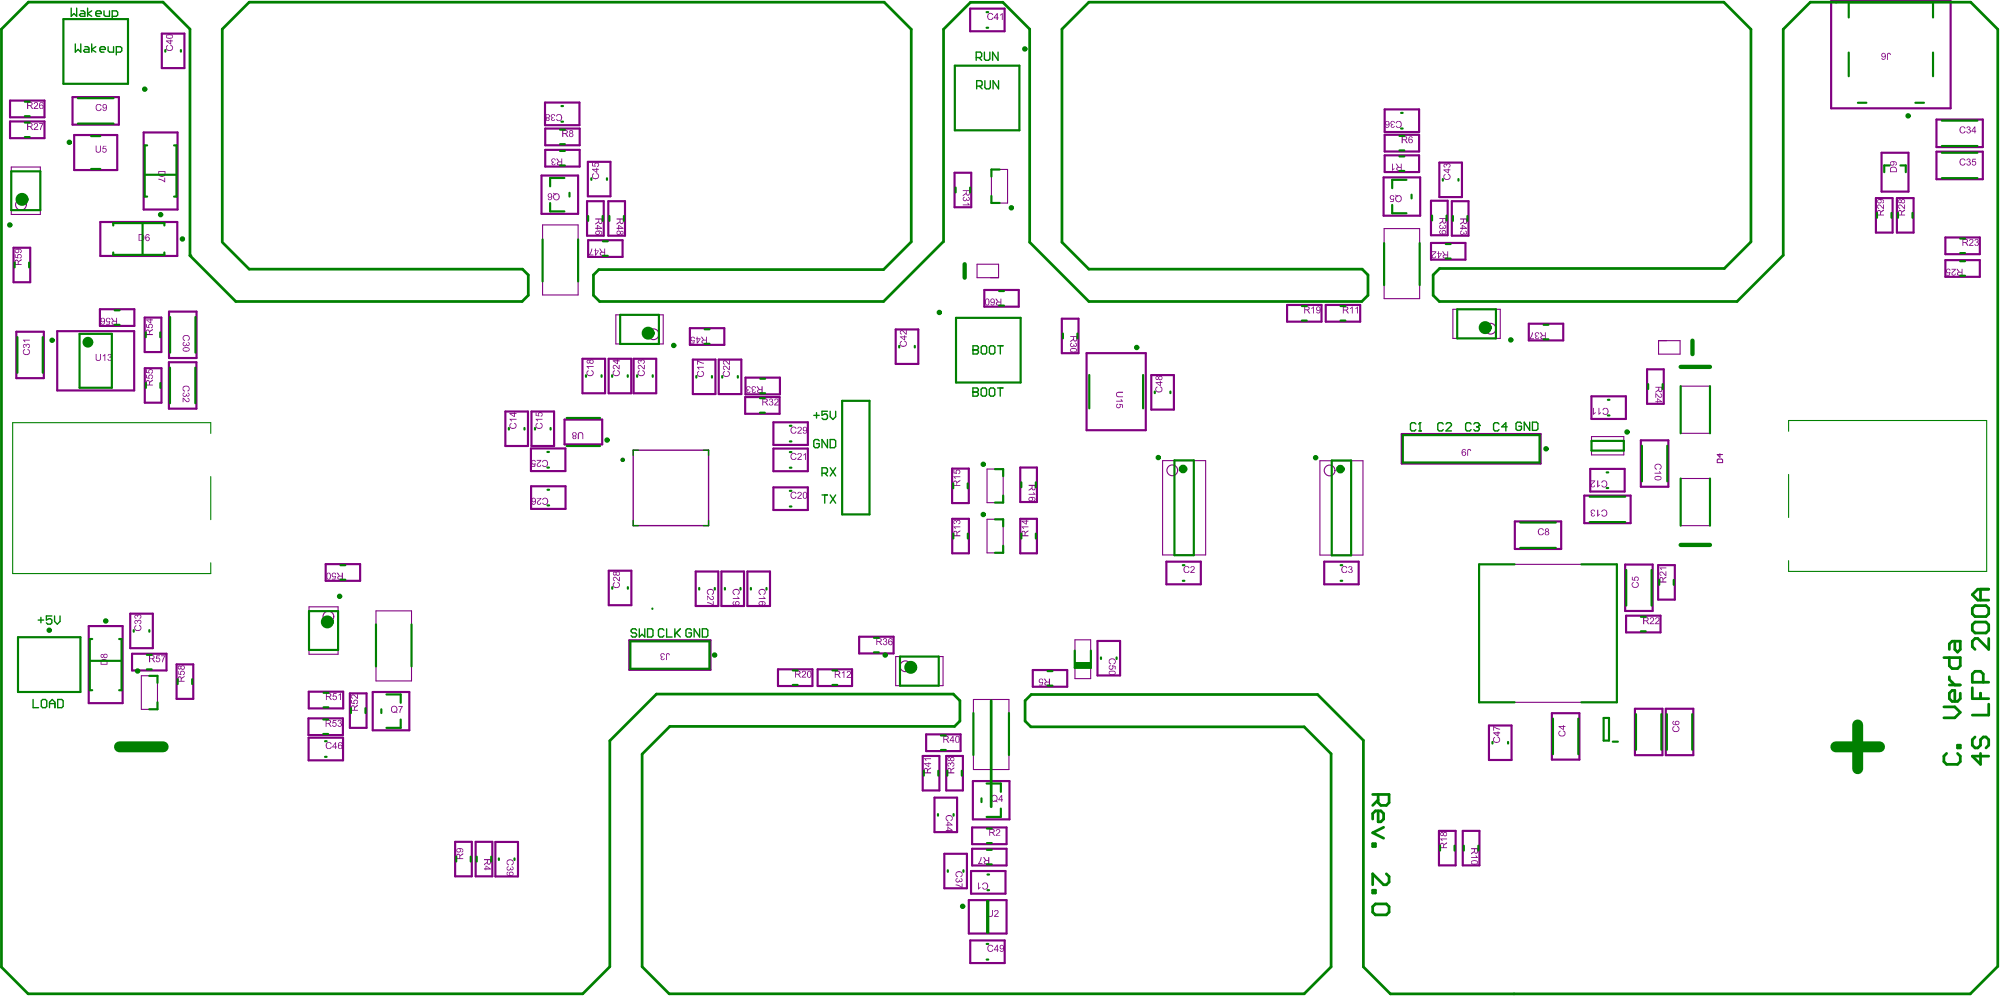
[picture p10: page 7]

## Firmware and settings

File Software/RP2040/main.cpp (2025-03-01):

#define __INSTANCE__
#include "appVariable.h"
#undef __INSTANCE__
#include <string.h>

int main()
{
    stdio_init_all();

    printf("START\n");
    IOManager.GPIO_init();
    uartHandler._uart_init();
    canHandler._can_init();
    IOManager.peripheralsInit();
    IOManager.bootfinished();

    while (1)
    {
        uartHandler._uart_mainLoop();
        uartHandler._uart_get_from_USB();
        if (IO_OPERATION == 0)
            IO_OPERATION = UPDATE_VALUES;
        IOManager.mainLoop();

        if (uartHandler.UART_FLAG_USB == UART_MAIN_PROCESS) //Command to process
        {
            switch(BufferRxUSB[0])  //Depending on first character
            {
                case 0x21:  //Alarm ACK
                    printf("Alarm\n");
                    if (BufferRxUSB[1] == 0x31) //reset N1
                        BATTSTAT.alarmN1 = 0x00;
                    if (BufferRxUSB[1] == 0x32) //reset N2
                        BATTSTAT.alarmN2 = 0x00;
                    if (BufferRxUSB[1] == 0x33) //reset N3
                        BATTSTAT.alarmN3 = 0x00;
                    if (BufferRxUSB[1] == 0x52) //reset All
                    {
                        BATTSTAT.alarmN1 = 0x00;
                        BATTSTAT.alarmN2 = 0x00;
                        BATTSTAT.alarmN3 = 0x00;
                    }
                    uartHandler.UART_FLAG_USB = 0;
                    break;
                case 0x22:  //Shunt Update
                    printf("Buffer : %02X %02X %02X %02X %02X %02X %02X %02X\n",BufferRxUSB[0], BufferRxUSB[1], BufferRxUSB[2], BufferRxUSB[3], BufferRxUSB[4], BufferRxUSB[5], BufferRxUSB[6], BufferRxUSB[7]);
                    BATTSTAT.calibrationShuntValue = ((BufferRxUSB[1] << 8) | BufferRxUSB[2]);
                    FLASHMGR.updateParam();
                    IOManager.ImaxValue = (0.066 / BATTSTAT.calibrationShuntValue)*1000000;
                    printf("Shunt : %u\n",BATTSTAT.calibrationShuntValue);
                    uartHandler.UART_FLAG_USB = 0;
                    break;
                case 0x23:  //SN Update
                    //printf("Buffer : %02X %02X %02X %02X %02X %02X %02X %02X\n",BufferRxUSB[0], BufferRxUSB[1], BufferRxUSB[2], BufferRxUSB[3], BufferRxUSB[4], BufferRxUSB[5], BufferRxUSB[6], BufferRxUSB[7]);
                    BMS_SERIAL_NUMBER = (BufferRxUSB[1] << 24) | (BufferRxUSB[2] << 16) | (BufferRxUSB[3] << 8)  | BufferRxUSB[4];
                    printf("SN : %08X\n",BMS_SERIAL_NUMBER);
                    FLASHMGR.updateParam();
                    uartHandler.UART_FLAG_USB = 0;
                    break;   
                case 0x24:  //Verbose
                    if (!VERBOSE_ENABLED) printf("VERBOSE ENABLED\n");
                    else printf("VERBOSE DISABLED\n");
                    VERBOSE_ENABLED = !VERBOSE_ENABLED;
                    uartHandler.UART_FLAG_USB = 0;
                    break;   
                
                case 0x25:  //ADC Cells
                    printf("OCV Calc\n");
                    //I2C_0.Scan(i2c0);
                    /*printf("Cell 1 : %u V\n", BATTSTAT.Cell0.Voltage);
                    printf("Cell 2 : %u V\n", BATTSTAT.Cell1.Voltage);
                    printf("Cell 3 : %u V\n", BATTSTAT.Cell2.Voltage);
                    printf("Cell 4 : %u V\n", BATTSTAT.Cell3.Voltage);*/
                    BATTSTAT.Cell0.SoC = BATTSTAT.Cell0.estimateSoCFromVoltage(BATTSTAT.Cell0.Voltage/1000.0)*10;
                    BATTSTAT.Cell1.SoC = BATTSTAT.Cell1.estimateSoCFromVoltage(BATTSTAT.Cell1.Voltage/1000.0)*10;
                    BATTSTAT.Cell2.SoC = BATTSTAT.Cell2.estimateSoCFromVoltage(BATTSTAT.Cell2.Voltage/1000.0)*10;
                    BATTSTAT.Cell3.SoC = BATTSTAT.Cell3.estimateSoCFromVoltage(BATTSTAT.Cell3.Voltage/1000.0)*10;
                    //FLASHMGR.dumpEEPROM();
                    FLASHMGR.updateParam();
                    uartHandler.UART_FLAG_USB = 0;
                    break;
                
                case 0x26:  //Cells SN
                    printf("\n---\n");
                    BATTSTAT.cellNbrVMax.setBypassState(false);
                    BYPASS_ENABLED = !BYPASS_ENABLED;
                    if (BYPASS_ENABLED) printf("BYPASS ENABLED\n");
                    else printf("BYPASS DISABLED\n");
                    /*FLASHMGR.dumpEEPROM();
                    memcpy(BATTSTAT.Cell0.serialNumber, "02YCB65117400J89C0000001", 24);
                    memcpy(BATTSTAT.Cell1.serialNumber, "02YCB65117400J89C0000002", 24);
                    memcpy(BATTSTAT.Cell2.serialNumber, "02YCB65117400J89C0000003", 24);
                    memcpy(BATTSTAT.Cell3.serialNumber, "02YCB65117400J89C0000004", 24);
                    FLASHMGR.updateParam();*/
                    uartHandler.UART_FLAG_USB = 0;
                    break;

                default:
                    //printf("UNKNOWN COMMAND %02X\n", BufferRxUSB[0]);
                    uartHandler.UART_FLAG_USB = 0;
                    break;
            }
        }
    }
}

bool timer_1000ms_callback(repeating_timer_t *rt)
{
    IOManager.callBack();
    IOManager.mainLoop();
    IO_OPERATION = UPDATE_CURRENT;
    //BATTSTAT.randomVal();
    BATTSTAT.synthesisPack();
    //BATTSTAT.displayVal();
    canHandler._can_heartbeat();
    if (VERBOSE_ENABLED) BATTSTAT.sendGUIVal();

    // Read flash procedure
    //FLASHMGR.writeFlash();
    canHandler._can_send();
    return true;
}

bool timer_400ms_callback(repeating_timer_t *rt)
{
    IOManager.cells_update();
    IOManager.mainLoop();
    IO_OPERATION = READ_CELLS;
    //printf("BATTSTAT.balancingCounter %u\n", BATTSTAT.balancingCounter);
    if (BATTSTAT.balancingCounter++ > 200)
        BATTSTAT.balancingEnabled = 0; //No Bypass for a while until good measurements
    if (BATTSTAT.balancingCounter > 250)
    {
        BATTSTAT.balancingCounter = 0;
        BATTSTAT.balancingEnabled = 1;
    }

    canHandler.canTOCounter++;
    if ((canHandler.canTOCounter > 4) && (IOManager.loopCounterAlive++ == 3))   //Time to die
        IOManager.autoWakeUpEnd();
    return true;
}


void ext_callback_uart_rx()
{
    uartHandler.callback_uart_rx();
}

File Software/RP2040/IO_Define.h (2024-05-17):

#ifndef __IO_DEFINE__H
#define __IO_DEFINE__H

//Param HW
#define PIN_0                   0
#define PIN_1                   1
#define PIN_2                   2
#define PIN_3                   3
#define CAN_RX                  4
#define CAN_TX                  5
#define OUTPUT_LED              6
#define PIN_7                   7
#define BALANCING_C1            8
#define BALANCING_C2            9
#define TIMER_DONE              10
#define STAYING_ALIVE           11
#define I2C_SDA                 12
#define I2C_SCL                 13
#define BALANCING_C3            14
#define RESET                   15
#define UART_TX_PIN             16
#define UART_RX_PIN             17
#define PIN_18                  18
#define PIN_19                  19
#define PIN_20                  20
#define PIN_21                  21
#define BALANCING_C4            22
#define PIN_23                  23
#define PIN_24                  24
#define PIN_25                  25
#define CURRENT_SHUNT           26
#define RELAY_DRIVE             27
#define PIN_28                  28
#define PIN_29                  29

#endif

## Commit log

2023-10-06 Gerbers upload
2023-10-06 BoM & PnP files upload
    [BOM_PCB_4S_LFP_BMS__2023-03-03.csv, PickAndPlace_PCB_4S_LFP_BMS__2023-03-03.csv]
2023-10-06 Schematics Upload
2024-03-01 Added BMS GUI
2024-05-19 Uploaded HW_BMS_v2 files
    [Bill of Materials-ActiveBOM.xlsx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]
2024-08-05 Added ADC sensing. Temperature measurements & filtering
2025-02-28 Updated ADC Gains
